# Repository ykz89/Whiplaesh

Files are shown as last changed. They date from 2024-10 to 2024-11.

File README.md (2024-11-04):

# Whiplaesh
Inspired by Aespa's latest single '[Whiplash](https://www.youtube.com/watch?v=jWQx2f-CErU)'.

This is a 32 (23333+2) key wireless keyboard featuring:

- Nice!Nano (or alike) controller
- Hotswap or direct solder support for choc, gateron low profile, and MX switches
- Battery through holes for soldering a JST connector or direct wire
- On/off switch
- Reset switch
- VIK connector

## Case
Todo

## Build guide
Todo

## Firmware
Todo

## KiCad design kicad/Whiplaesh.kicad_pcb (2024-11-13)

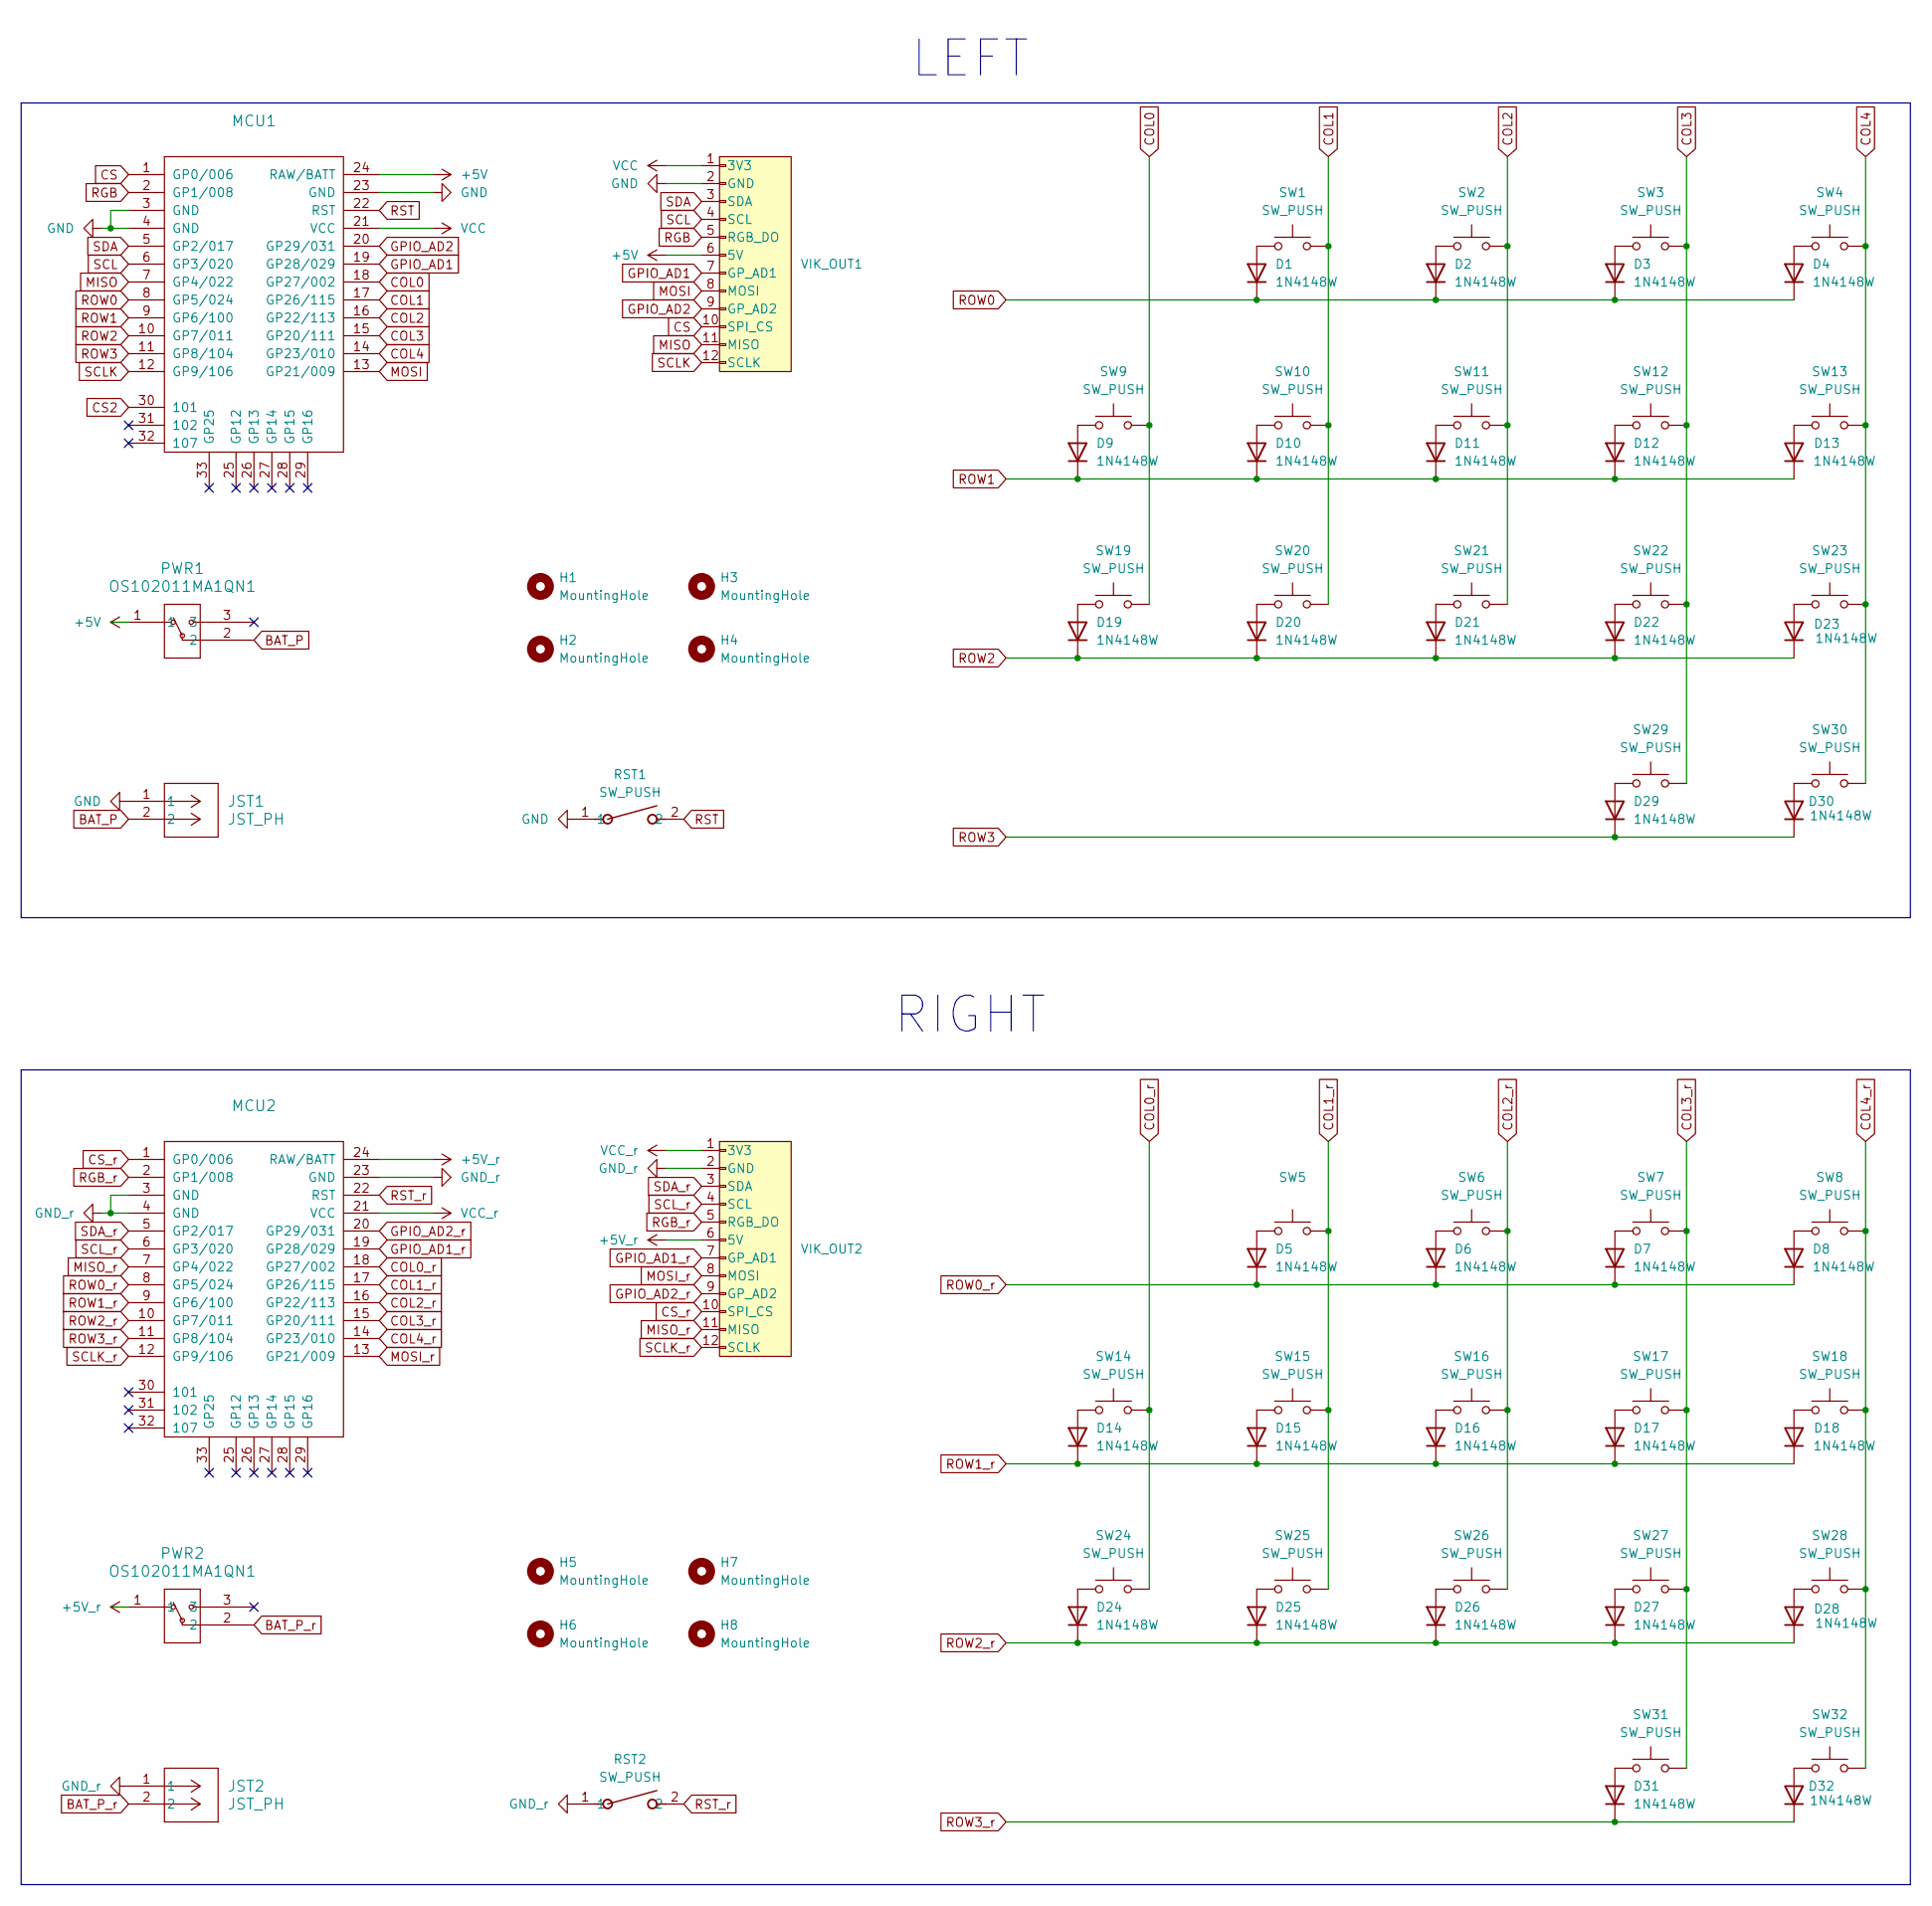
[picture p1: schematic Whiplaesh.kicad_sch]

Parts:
D1, D2, D3, D4, D5, D6, D7, D8, D9, D10, D11, D12, D13, D14, D15, D16, D17, D18, D19, D20, D21, D22, D23, D24, D25, D26, D27, D28, D29, D30, D31, D32: 1N4148W; D3_TH_SMD
H1, H2, H3, H4, H5, H6, H7, H8: MountingHole; MountingHole_2.2mm_M2
JST1, JST2: JST_PH; JST_PH_S2B-PH-K_1x02_P2.00mm_Horizontal
MCU1, MCU2: ArduinoProMicro
PWR1, PWR2: OS102011MA1QN1; OS102011MA1QN1_CNK
RST1, RST2: SW_PUSH; SW_SKHLACA010_ALPS
SW1, SW2, SW3, SW4, SW5, SW6, SW7, SW8, SW9, SW10, SW11, SW12, SW13, SW14, SW15, SW16, SW17, SW18, SW19, SW20, SW21, SW22, SW23, SW24, SW25, SW26, SW27, SW28, SW29, SW30, SW31, SW32: SW_PUSH; gateron-ks27-choc-v1-mx-soldered-and-hotswap
VIK_OUT1, VIK_OUT2: vik-keyboard-connector-horizontal

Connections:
+5V: MCU1.24 (RAW/BATT), PWR1.1, VIK_OUT1.6 (5V)
+5V_r: MCU2.24 (RAW/BATT), PWR2.1, VIK_OUT2.6 (5V)
BAT_P: JST1.2, PWR1.2
BAT_P_r: JST2.2, PWR2.2
COL0: MCU1.18 (GP27/002), SW9.2, SW19.2
COL0_r: MCU2.18 (GP27/002), SW14.2, SW24.2
COL1: MCU1.17 (GP26/115), SW1.2, SW10.2, SW20.2
COL1_r: MCU2.17 (GP26/115), SW5.2, SW15.2, SW25.2
COL2: MCU1.16 (GP22/113), SW2.2, SW11.2, SW21.2
COL2_r: MCU2.16 (GP22/113), SW6.2, SW16.2, SW26.2
COL3: MCU1.15 (GP20/111), SW3.2, SW12.2, SW22.2, SW29.2
COL3_r: MCU2.15 (GP20/111), SW7.2, SW17.2, SW27.2, SW31.2
COL4: MCU1.14 (GP23/010), SW4.2, SW13.2, SW23.2, SW30.2
COL4_r: MCU2.14 (GP23/010), SW8.2, SW18.2, SW28.2, SW32.2
CS: MCU1.1 (GP0/006), VIK_OUT1.10 (SPI_CS)
CS_r: MCU2.1 (GP0/006), VIK_OUT2.10 (SPI_CS)
GND: JST1.1, MCU1.3 (GND), MCU1.4 (GND), MCU1.23 (GND), RST1.1, VIK_OUT1.2 (GND)
GND_r: JST2.1, MCU2.3 (GND), MCU2.4 (GND), MCU2.23 (GND), RST2.1, VIK_OUT2.2 (GND)
GPIO_AD1: MCU1.19 (GP28/029), VIK_OUT1.7 (GP_AD1)
GPIO_AD1_r: MCU2.19 (GP28/029), VIK_OUT2.7 (GP_AD1)
GPIO_AD2: MCU1.20 (GP29/031), VIK_OUT1.9 (GP_AD2)
GPIO_AD2_r: MCU2.20 (GP29/031), VIK_OUT2.9 (GP_AD2)
MISO: MCU1.7 (GP4/022), VIK_OUT1.11 (MISO)
MISO_r: MCU2.7 (GP4/022), VIK_OUT2.11 (MISO)
MOSI: MCU1.13 (GP21/009), VIK_OUT1.8 (MOSI)
MOSI_r: MCU2.13 (GP21/009), VIK_OUT2.8 (MOSI)
unnamed: D1.2 (A), SW1.1
unnamed: D2.2 (A), SW2.1
unnamed: D3.2 (A), SW3.1
unnamed: D4.2 (A), SW4.1
unnamed: D5.2 (A), SW5.1
unnamed: D6.2 (A), SW6.1
unnamed: D7.2 (A), SW7.1
unnamed: D8.2 (A), SW8.1
unnamed: D9.2 (A), SW9.1
unnamed: D10.2 (A), SW10.1
unnamed: D11.2 (A), SW11.1
unnamed: D12.2 (A), SW12.1
unnamed: D13.2 (A), SW13.1
unnamed: D14.2 (A), SW14.1
unnamed: D15.2 (A), SW15.1
unnamed: D16.2 (A), SW16.1
unnamed: D17.2 (A), SW17.1
unnamed: D18.2 (A), SW18.1
unnamed: D19.2 (A), SW19.1
unnamed: D20.2 (A), SW20.1
unnamed: D21.2 (A), SW21.1
unnamed: D22.2 (A), SW22.1
unnamed: D23.2 (A), SW23.1
unnamed: D24.2 (A), SW24.1
unnamed: D25.2 (A), SW25.1
unnamed: D26.2 (A), SW26.1
unnamed: D27.2 (A), SW27.1
unnamed: D28.2 (A), SW28.1
unnamed: D29.2 (A), SW29.1
unnamed: D30.2 (A), SW30.1
unnamed: D31.2 (A), SW31.1
unnamed: D32.2 (A), SW32.1
RGB: MCU1.2 (GP1/008), VIK_OUT1.5 (RGB_DO)
RGB_r: MCU2.2 (GP1/008), VIK_OUT2.5 (RGB_DO)
ROW0: D1.1 (K), D2.1 (K), D3.1 (K), D4.1 (K), MCU1.8 (GP5/024)
ROW0_r: D5.1 (K), D6.1 (K), D7.1 (K), D8.1 (K), MCU2.8 (GP5/024)
ROW1: D9.1 (K), D10.1 (K), D11.1 (K), D12.1 (K), D13.1 (K), MCU1.9 (GP6/100)
ROW1_r: D14.1 (K), D15.1 (K), D16.1 (K), D17.1 (K), D18.1 (K), MCU2.9 (GP6/100)
ROW2: D19.1 (K), D20.1 (K), D21.1 (K), D22.1 (K), D23.1 (K), MCU1.10 (GP7/011)
ROW2_r: D24.1 (K), D25.1 (K), D26.1 (K), D27.1 (K), D28.1 (K), MCU2.10 (GP7/011)
ROW3: D29.1 (K), D30.1 (K), MCU1.11 (GP8/104)
ROW3_r: D31.1 (K), D32.1 (K), MCU2.11 (GP8/104)
RST: MCU1.22 (RST), RST1.2
RST_r: MCU2.22 (RST), RST2.2
SCL: MCU1.6 (GP3/020), VIK_OUT1.4 (SCL)
SCLK: MCU1.12 (GP9/106), VIK_OUT1.12 (SCLK)
SCLK_r: MCU2.12 (GP9/106), VIK_OUT2.12 (SCLK)
SCL_r: MCU2.6 (GP3/020), VIK_OUT2.4 (SCL)
SDA: MCU1.5 (GP2/017), VIK_OUT1.3 (SDA)
SDA_r: MCU2.5 (GP2/017), VIK_OUT2.3 (SDA)
VCC: MCU1.21 (VCC), VIK_OUT1.1 (3V3)
VCC_r: MCU2.21 (VCC), VIK_OUT2.1 (3V3)

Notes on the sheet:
LEFT
RIGHT

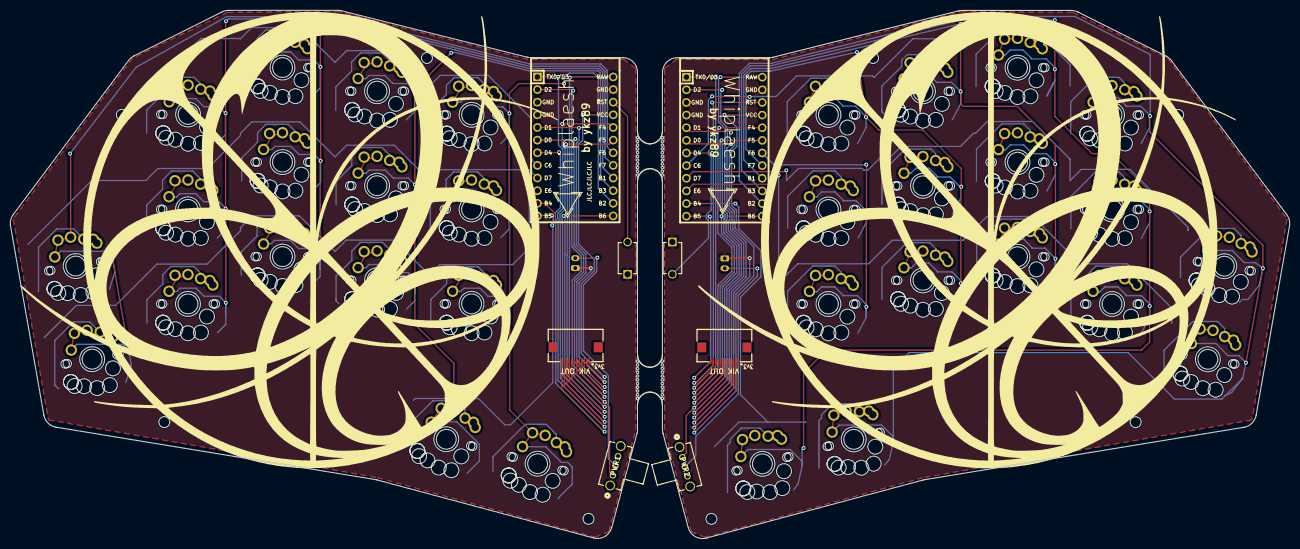
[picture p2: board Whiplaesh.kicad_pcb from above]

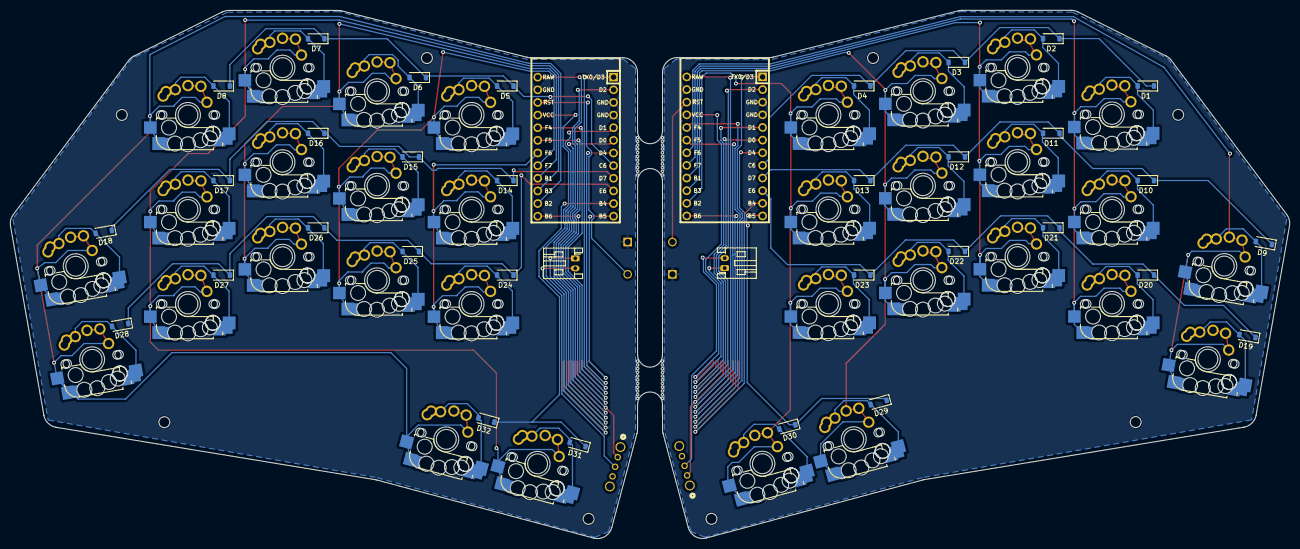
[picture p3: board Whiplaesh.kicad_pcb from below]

Board: 2 copper layers, 257.1 x 106.2 mm, 84 parts (34 on the bottom side), 78 nets.

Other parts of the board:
mouse-bite-5mm-slot, mouse-bite-5mm-slot#2: VAL**; mouse-bite-5mm-slot

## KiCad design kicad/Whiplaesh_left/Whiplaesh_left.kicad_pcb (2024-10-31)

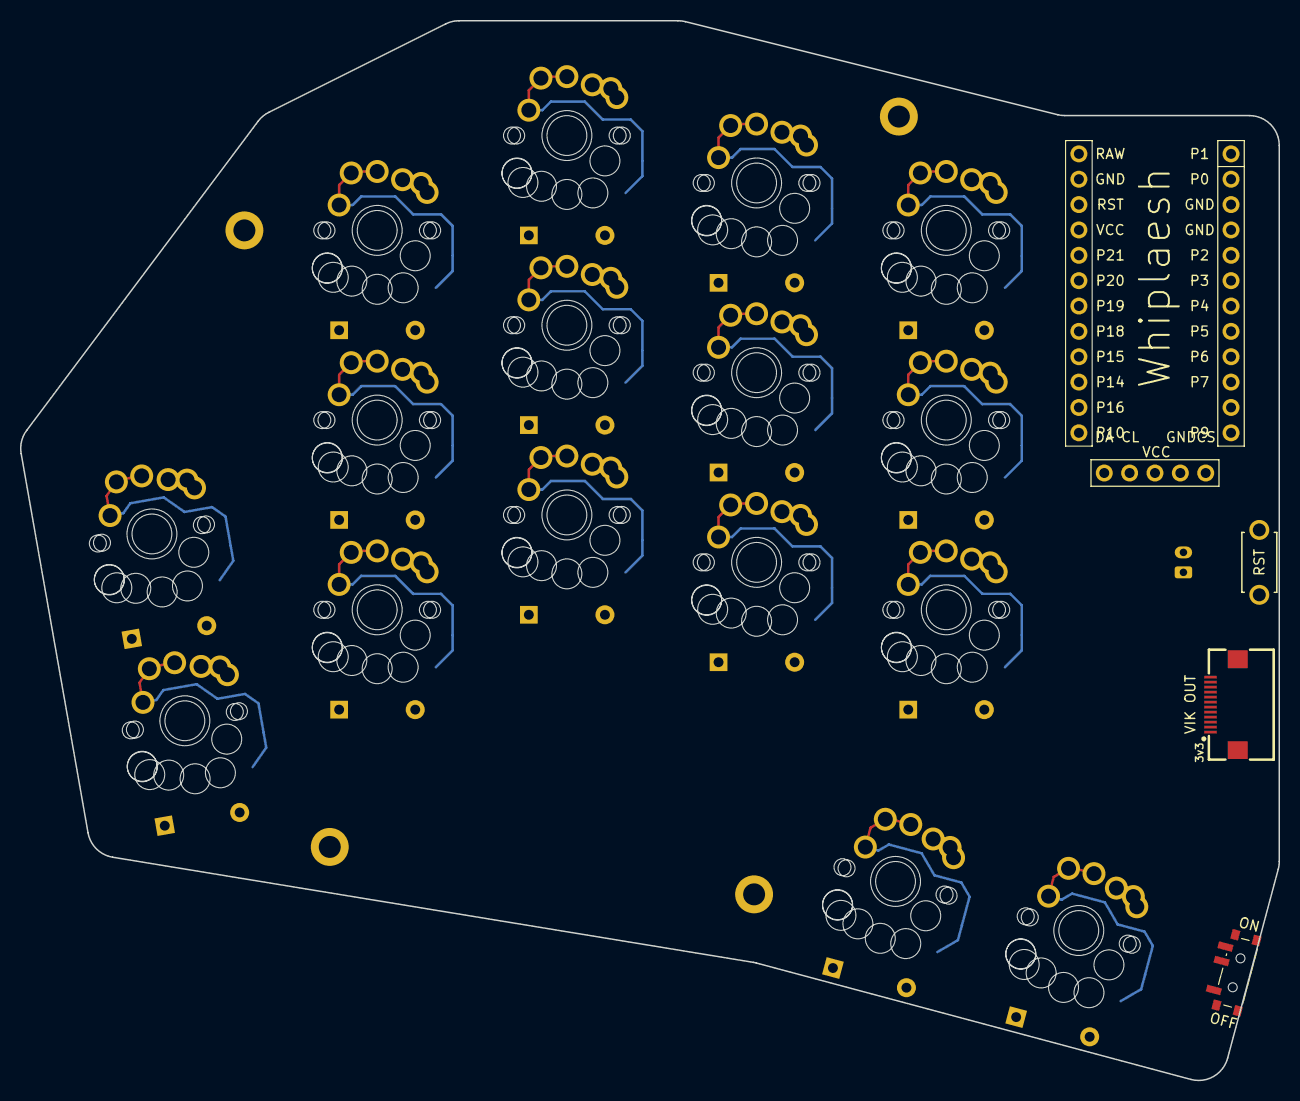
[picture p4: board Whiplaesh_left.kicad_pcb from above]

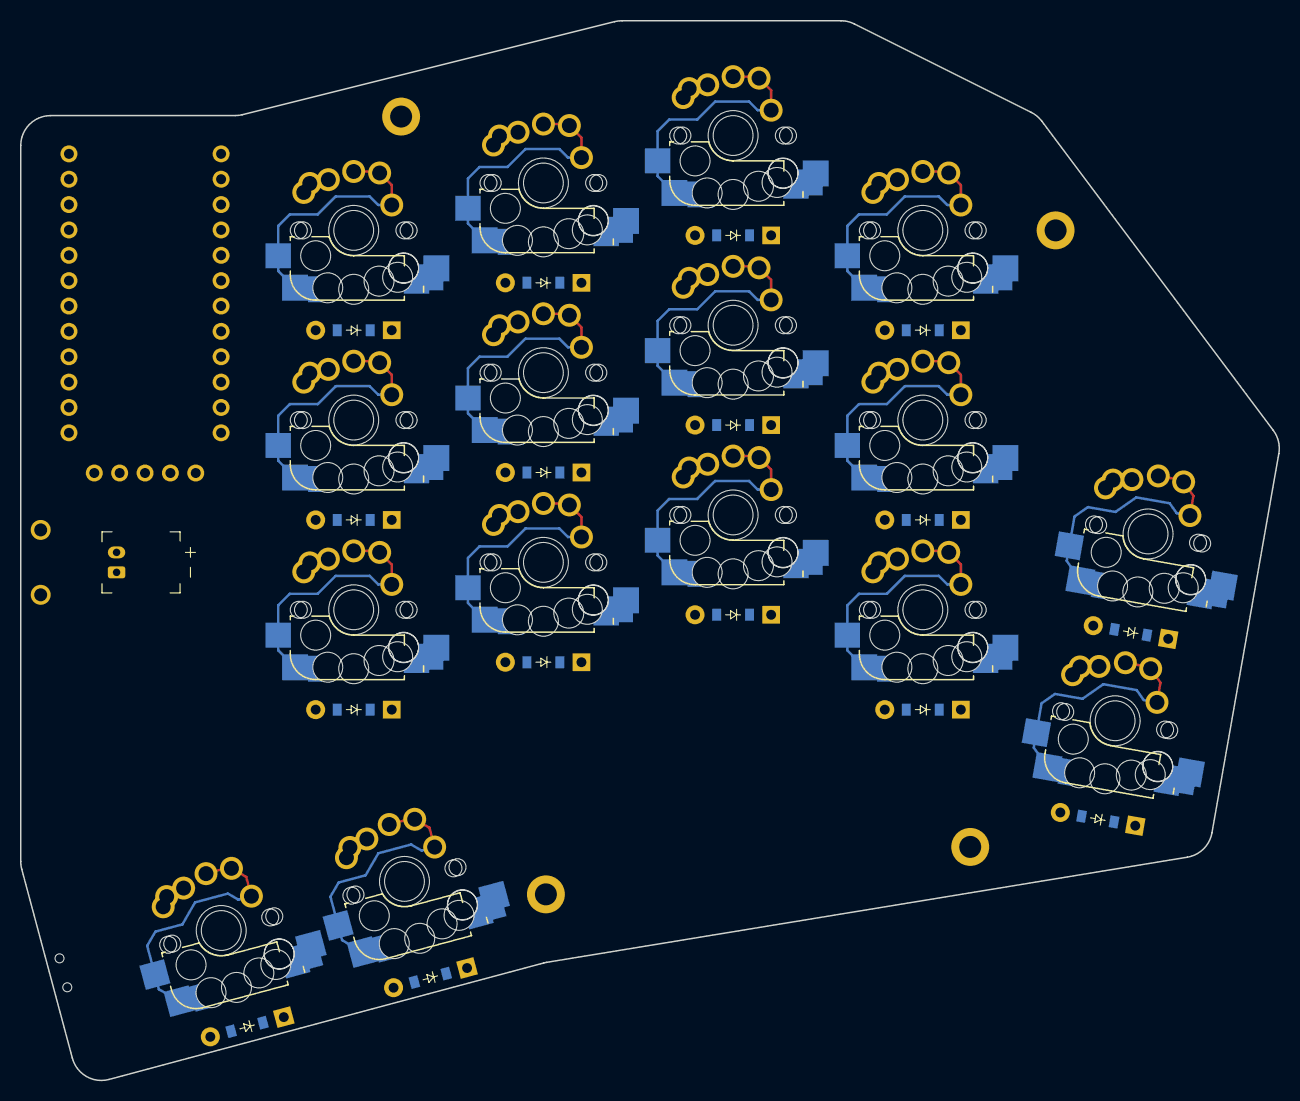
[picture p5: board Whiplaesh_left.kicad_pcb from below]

Board: 2 copper layers, 126.1 x 106.1 mm, 42 parts (33 on the bottom side), 38 nets.

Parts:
D1, D2, D3, D4, D5, D6, D7, D8, D9, D10, D11, D12, D13, D14, D15, D16: diode_tht_sod123
DISP1: display_nice_view
H1, H2, H3, H4: mounting_hole_plated
JST1: battery_connector_jst_ph_2
MCU1: mcu_nice_nano
PWR1: power_switch_smd_side
RST1: reset_switch_tht_top
SW1, SW2, SW3, SW4, SW5, SW6, SW7, SW8, SW9, SW10, SW11, SW12, SW13, SW14, SW15, SW16: ks27-choc-v1-mx-soldered-and-hotswap
VIK_OUT1: vik-keyboard-connector-horizontal

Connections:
BAT_P: JST1.2, PWR1.3
GND: DISP1.2, JST1.1, MCU1.3, MCU1.4, MCU1.23, RST1.2, VIK_OUT1.2
P0: MCU1.2, VIK_OUT1.5
P1: MCU1.1, VIK_OUT1.10
P2: MCU1.5, VIK_OUT1.3
P3: MCU1.6, VIK_OUT1.4
P4: D5.1, D8.1, D11.1, D14.1, MCU1.7, VIK_OUT1.11
P5: D2.1, D4.1, D7.1, D10.1, D13.1, MCU1.8
P6: D1.1, D3.1, D6.1, D9.1, D12.1, MCU1.9
P8: D15.1, D16.1, MCU1.11
P9: DISP1.4, MCU1.12, VIK_OUT1.12
P10: DISP1.5, MCU1.13, VIK_OUT1.8
P14: MCU1.15, SW9.1, SW10.1, SW11.1, SW15.1
P15: MCU1.16, SW6.1, SW7.1, SW8.1
P16: MCU1.14, SW12.1, SW13.1, SW14.1, SW16.1
P18: MCU1.17, SW3.1, SW4.1, SW5.1
P19: MCU1.18, SW1.1, SW2.1
P20: MCU1.19, VIK_OUT1.9
P21: MCU1.20, VIK_OUT1.7
RAW: MCU1.24, PWR1.2, VIK_OUT1.6
RST: MCU1.22, RST1.1
VCC: DISP1.3, MCU1.21, VIK_OUT1.1
index_bottom: D9.2, SW9.2
index_home: D10.2, SW10.2
index_top: D11.2, SW11.2
inner_bottom: D12.2, SW12.2
inner_home: D13.2, SW13.2
inner_top: D14.2, SW14.2
left_cluster: D15.2, SW15.2
middle_bottom: D6.2, SW6.2
middle_home: D7.2, SW7.2
middle_top: D8.2, SW8.2
pinky_bottom: D1.2, SW1.2
pinky_home: D2.2, SW2.2
right_cluster: D16.2, SW16.2
ring_bottom: D3.2, SW3.2
ring_home: D4.2, SW4.2
ring_top: D5.2, SW5.2

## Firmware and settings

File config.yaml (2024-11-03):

meta:
  engine: 4.1.0 # Min Ergogen version for KiCad 8 footprints
  name: Whiplaesh
  version: 0.1
  author: ykz89

units:
  # Proxy Spacing Variables
  kx: u
  ky: u
  # Padding Variables
  px: kx + 4
  py: ky + 4
  # MX switch hole
  sx: kx - 5
  sy: ky - 5

  # Physical measures
  pwr_trace_width: 0.25
  gnd_trace_width: 0.25
  signal_trace_width: 0.15
  via_size: 0.56 # JLCPCB min 0.56 | KiCad default 0.8
  via_drill: 0.3 # JLCPCB min 0.3 | KiCad default 0.4

points:
  zones:
    matrix:
      # Fix placement on KiCad sheet.
      anchor:
        shift: [100, -100]
      columns:
        pinky:
          key:
            splay: 15
          rows.top.skip: true
        ring:
          key:
            splay: -10
            stagger: 0.4u
            spread: 1.1u
        middle:
          key:
            stagger: 0.5u
        index:
          key:
            stagger: -0.25u
        inner:
          key:
            stagger: -0.25u
      rows:
        bottom:
        home:
        top:
    thumbs:
      anchor:
        ref: matrix_inner_top
        shift: [0.25u, -1.5u]
      columns:
        left:
          key:
            splay: -15
        right:
      rows:
        cluster:
          shift: [0, -2u]
  rotate: -5
  mirror: &mirror
      ref: matrix_inner_top
      distance: 5u
outlines:
  keys:
    - what: rectangle
      where: true
      size: [sx, sy]
  board_left:
    - what: polygon
      operation: stack
      fillet: 3
      points:
        # Top
        - ref: matrix_inner_top
          shift: [1.45px,0.5py]
        - ref: matrix_inner_top
          shift: [0.5px,0.5py]
        - ref: matrix_middle_top
          shift: [0.5px,0.5py]
        - ref: matrix_middle_top
          shift: [-0.5px,0.5py]
        - ref: matrix_ring_top
          shift: [-0.5px,0.5py]
        - ref: matrix_pinky_home
          shift: [-0.5px,0.5py]
        - ref: matrix_pinky_bottom
          shift: [-0.5px,-0.5py]
        - ref: thumbs_left_cluster
          shift: [-0.5px,-0.5py]
        - ref: thumbs_right_cluster
          shift: [0.77px,-0.5py]
        - ref: thumbs_right_cluster
          shift: [0.77px,0.5py]
  board_right:
    - what: polygon
      operation: stack
      fillet: 3
      points:
        # Top
        - ref: mirror_matrix_inner_top
          shift: [1.45px,0.5py]
        - ref: mirror_matrix_inner_top
          shift: [0.5px,0.5py]
        - ref: mirror_matrix_middle_top
          shift: [0.5px,0.5py]
        - ref: mirror_matrix_middle_top
          shift: [-0.5px,0.5py]
        - ref: mirror_matrix_ring_top
          shift: [-0.5px,0.5py]
        - ref: mirror_matrix_pinky_home
          shift: [-0.5px,0.5py]
        - ref: mirror_matrix_pinky_bottom
          shift: [-0.5px,-0.5py]
        - ref: mirror_thumbs_left_cluster
          shift: [-0.5px,-0.5py]
        - ref: mirror_thumbs_right_cluster
          shift: [0.77px,-0.5py]
        - ref: mirror_thumbs_right_cluster
          shift: [0.77px,0.5py]
  combo_left:
    - name: board_left
    - operation: subtract
      name: keys
  combo_right:
    - name: board_right
    - operation: subtract
      name: keys
pcbs:
  Whiplaesh:
    template: kicad8
    outlines:
      left:
        outline: board_left
      right:
        outline: board_right
    footprints:
      glp_hotswap:
        what: fingerpunch/ks27-choc-v1-mx-soldered-and-hotswap
        where: /^(matrix_|thumbs_|mirror_matrix_|mirror_thumbs_).*/
        params:
          designator: SW
          side: B
          include_switch_hole: true
          include_traces: true
          from: "{{column_net}}"
          to: "{{colrow}}"
      diode:
        what: ceoloide/diode_tht_sod123
        where: /^(matrix_|thumbs_|mirror_matrix_|mirror_thumbs_).*/
        params:
          include_tht: true
          from: "{{colrow}}"
          to: "{{row_net}}"
        adjust:
          shift: [0, -10]
      mcu_l:
        what: ceoloide/mcu_nice_nano
        params:
          designator: MCU1
          side: "F"
          reverse_mount: true
          show_silk_labels_on_both_sides: false
        where:
          ref: matrix_inner_top
          shift: [1.1u,-0.265u]
          rotate: 0
      mcu_r:
        what: ceoloide/mcu_nice_nano
        params:
          designator: MCU2
          side: "F"
          reverse_mount: true
          show_silk_labels_on_both_sides: false
        where:
          ref: mirror_matrix_inner_top
          shift: [1.1u,-0.265u]
          rotate: 0
      vik_l:
        what: fingerpunch/vik-keyboard-connector-horizontal
        where:
          ref: matrix_inner_bottom
          shift: [1.5u,-0.5u]
          rotate: 90
        params:
          designator: VIK_OUT1
      vik_r:
        what: fingerpunch/vik-keyboard-connector-horizontal
        where:
          ref: mirror_matrix_inner_bottom
          shift: [1.5u,-0.5u]
          rotate: 90
        params:
          designator: VIK_OUT2
      jst_l:
        what: ceoloide/battery_connector_jst_ph_2
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

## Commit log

2024-10-26 Add keyswitch footprint
2024-10-26 Add footprints
2024-10-27 Fix and add switch footprint
    [board_left.dxf, board_right.dxf, combo_left.dxf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]
2024-10-27 Add gitignore
    [board_left.dxf, board_right.dxf, combo_left.dxf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]
2024-10-28 Add traces to switch footprint
2024-10-30 Move ergogen footprints to separate repo, Make schematics
    [Whiplaesh.kicad_pcb, Whiplaesh.kicad_sch]
2024-10-30 Add missing connections, fix diodes references, fix shared pins on vik connector
    [Whiplaesh.kicad_pcb, Whiplaesh.kicad_sch]
2024-10-31 Separate left and right, add kicad footprints and symbols
    [Whiplaesh.kicad_pcb, Whiplaesh.kicad_sch, Whiplaesh_left.kicad_pcb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]
2024-11-01 add right board in ergogen config
    [Whiplaesh.kicad_pcb, Whiplaesh.kicad_sch, Whiplaesh_left.kicad_sch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]
2024-11-03 Remove nice!view and update schematics and pcb
    [Whiplaesh.kicad_pcb, Whiplaesh.kicad_sch]
2024-11-04 Redo routing, add ground plane, add fingerpunch footprints
    [Whiplaesh.kicad_pcb, Whiplaesh.kicad_sch]
2024-11-04 Fix silkscreen, add production files
    [Whiplaesh-CuBottom.gbr, Whiplaesh-CuTop.gbr, Whiplaesh-EdgeCuts.gbr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]
2024-11-04 Tentatively add bottom plate
    [Whiplaesh-CuBottom.gbr, Whiplaesh-CuTop.gbr, Whiplaesh-EdgeCuts.gbr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]
2024-11-04 Mirror ground fill, fix battery connector position
    [Whiplaesh.kicad_pcb]
2024-11-04 Fix dangling traces and references
    [Whiplaesh-CuBottom.gbr, Whiplaesh-CuTop.gbr, Whiplaesh-EdgeCuts.gbr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]
2024-11-13 Add missing trace
    [Whiplaesh.kicad_pcb]
